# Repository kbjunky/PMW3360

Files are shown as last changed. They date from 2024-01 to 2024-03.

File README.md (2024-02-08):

# **PMW3360/PMW3389**
PMW3360/PMW3389 breakout board for trackball/mouse. Compatible with 3.3V - 5V MCUs.

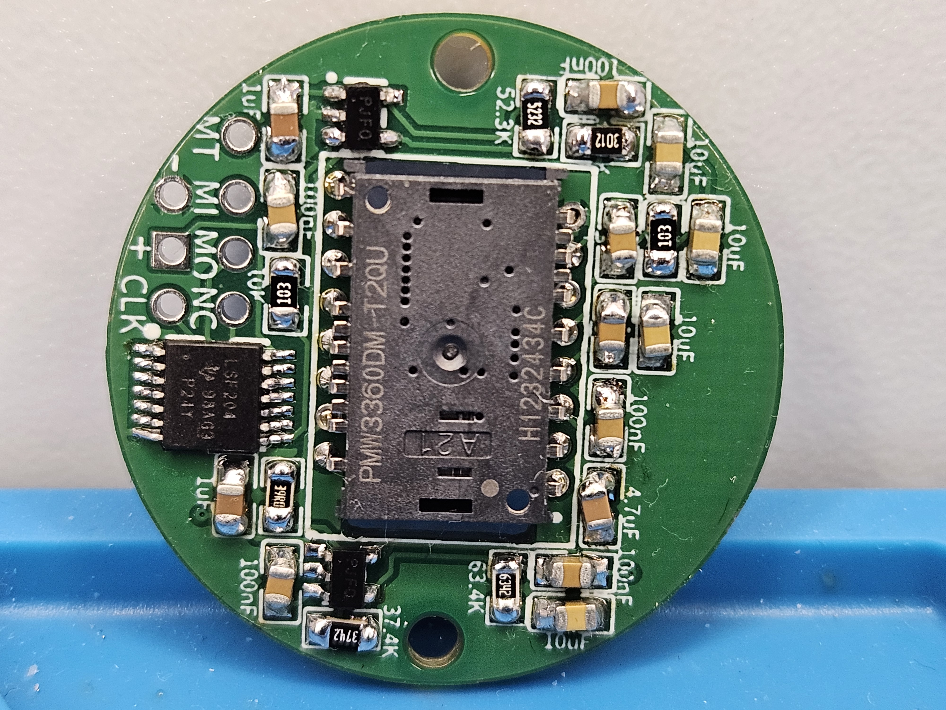
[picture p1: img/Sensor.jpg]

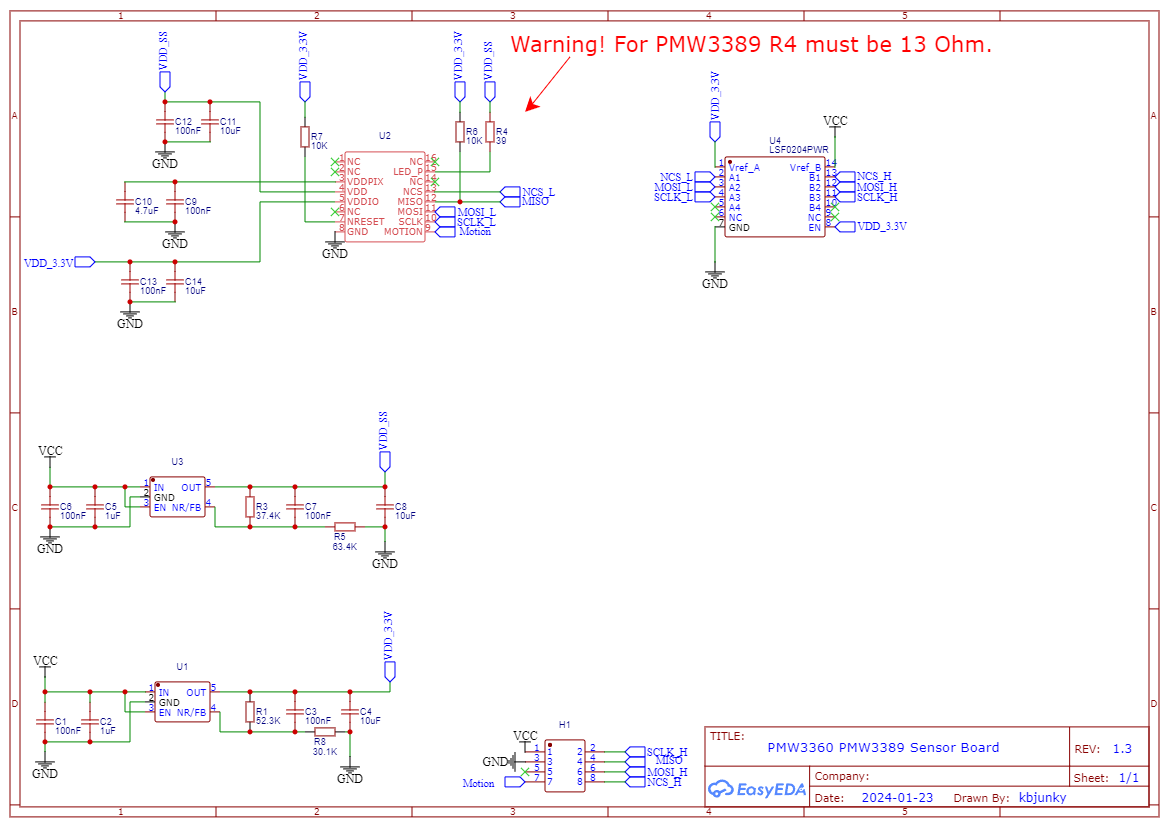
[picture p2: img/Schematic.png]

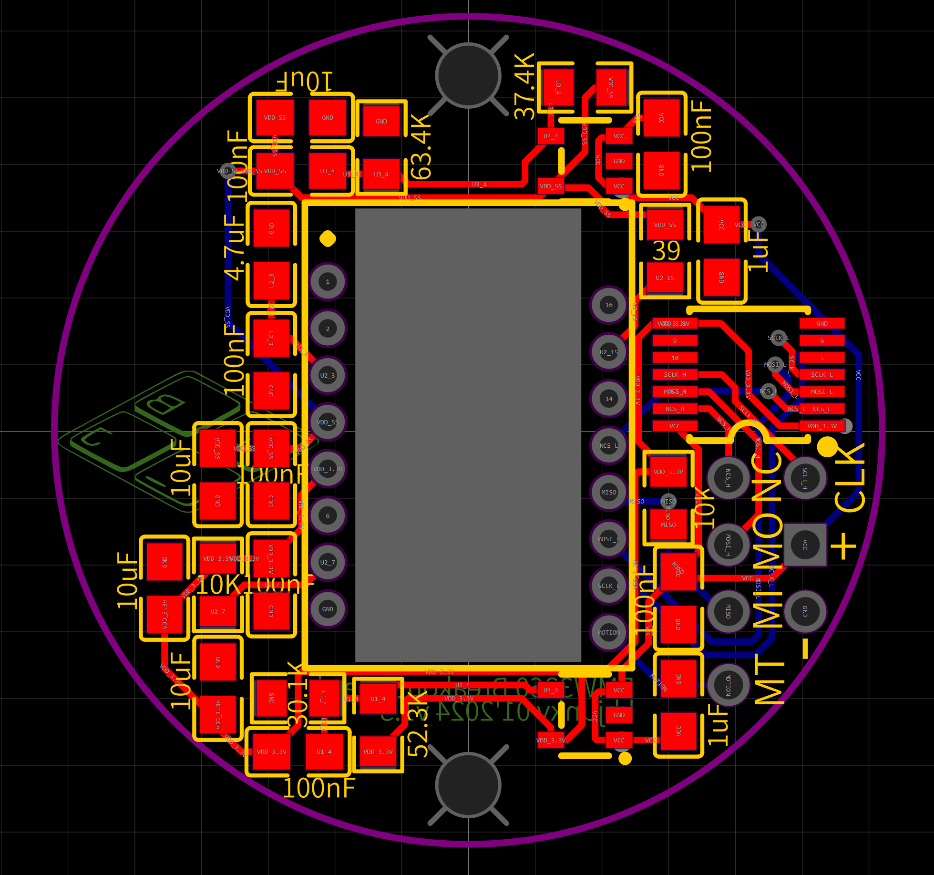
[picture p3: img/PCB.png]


## **BOM**
|Name |Value  |Footprint  |Qty |
|:---: |:---:  |:---: |:---:  |
|C1,C3,C6,C7,C9,C12,C13 |100nF  |0805 |7 |
|C2,C5 |1uF |0805 |2 |
|C4,C8,C11,C14 |10uF |0805 |4 |
|C10 |4.7uF  |0805 |1 |
|U2 | |TSSOP-14 |1 |
|R1 |52.3k  |0805 |1 |
|R3 |37.4k  |0805 |1 |
|R4 |39/13* |0805 |1 |
|R5 |63.4k  |0805 |1 |
|R6,R7 |10k |0805 |2 |
|R8 |30.1k  |0805 |1 |
|U1,U3 | |SOT23 |2 |
|PMW3360/PMW3389 + lens | | |1 |
||

Remarks:
*   PCB/Holes are the same size/placement as for [ADNS-9800](https://github.com/kbjunky/ADNS9800) thus making it easier to swap sensors for existing projects. Also in between mounting holes fits ProMicro or Rapsperry Pico thus making it possible to fit MCU underneath the sensor for a compact build.
*   U1, U3 are TPS73601DBVR LDO voltage stabilizers
*   U2 is LSF0204PWR logic level translator
*   For PMW3389 R4 must be 13 Ohm
*   Sensor together with the lens can be obtained from [Aliexpress](https://www.aliexpress.com/item/33056166849.html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)

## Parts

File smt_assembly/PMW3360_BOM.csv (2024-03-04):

ID | Name | Designator | Footprint | Quantity | Manufacturer Part | Manufacturer | Supplier | Supplier Part | Price
1 | LSF0204PWR | U4 | TSSOP-14_L5.0-W4.4-P0.65-LS6.4-BL | 1 | LSF0204PWR | TI(德州仪器) | LCSC | C202288 | 0.683
2 | 100nF | C1,C3,C6,C7,C9,C12,C13 | C0805 | 7 | FM21X104K101ECG | Prosperity Dielectrics | LCSC | C148241 | 0.006
3 | 1uF | C2,C5 | C0805 | 2 | 0805B105K160NT | FH | LCSC | C89259 | 0.01
4 | 10uF | C4,C8,C11,C14 | C0805 | 4 | 0805F106M250NT | Guangdong Fenghua Advanced Tech | LCSC | C39060 | 0.029
5 | 4.7uF | C10 | C0805 | 1 | CS2012X5R475K500NRE | Samwha Capacitor | LCSC | C513770 | 0.014
6 | 52.3K | R1 | R0805 | 1 | RTT055232FTP | RALEC | LCSC | C104392 | 0.002
7 | 37.4K | R3 | R0805 | 1 | HPCR0805F37K4K9 | ResistorToday | LCSC | C365295 | 0.011
8 | 39 | R4 | R0805 | 1 | CR0805-FX-39R0ELF | BOURNS | LCSC | C204475 | 0.012
9 | 63.4K | R5 | R0805 | 1 | WR08X6342FTL | WTC | LCSC | C170947 | 0.007
10 | 10K | R6,R7 | R0805 | 2 | RTT05103JTP | RALEC | LCSC | C103914 | 0.001
11 | 30.1K | R8 | R0805 | 1 | 0805W8F3012T5E | UniOhm | LCSC | C21841 | 0.002
12 | TPS73601DBVR | U1,U3 | SOT-23-5_L3.0-W1.7-P0.95-LS2.8-BR | 2 | TPS73601DBVR | TI | LCSC | C59200 | 0.813
13 | PMW3360DM-T2QU | U2 | PMW3360DM-T2QU.PACK | 1 | PMW3360DM-T2QU

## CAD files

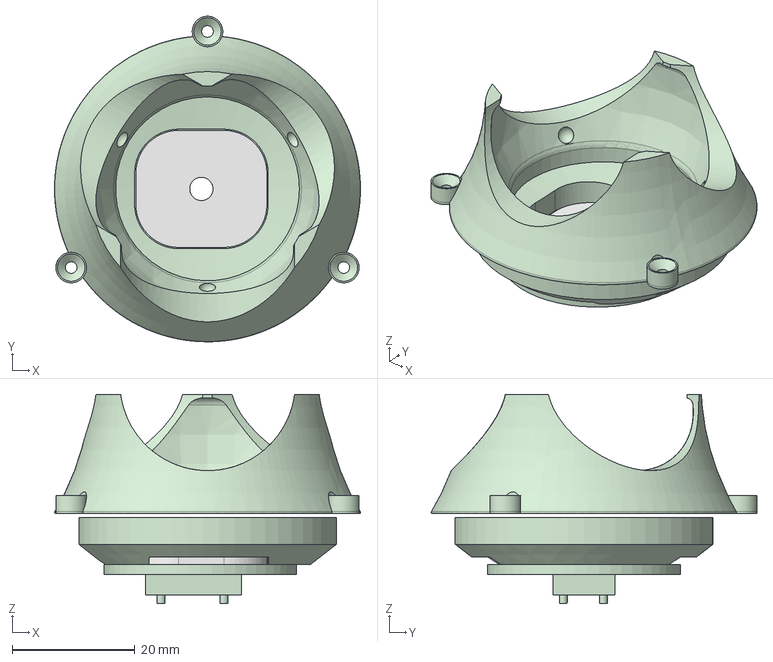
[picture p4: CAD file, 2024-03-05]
step/34mm_ball_trackball.stp
50.0 x 53.2 x 34.2 mm

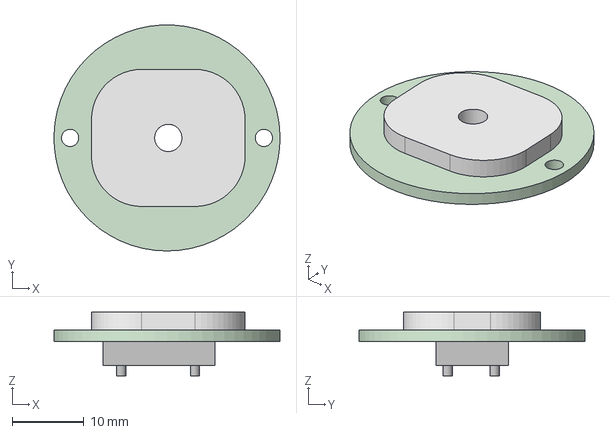
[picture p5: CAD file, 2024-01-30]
step/PMW3360.stp
31.5 x 31.5 x 8.85 mm

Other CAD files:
stl/pmw3360.stl

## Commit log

2022-11-10 Create pmw3360.stl
    Added STL for the assembled board
    [pmw3360.stl]
2024-01-30 Added step file
    [PMW3360.stp]
2024-02-08 Updated with logic shifter
    - added logic level shifter instead of Zener diodes
    - now supports PMW3389 with R4 swap to 13 Ohm
2024-03-04 Added SMT assembly required files
    +BOM
    +Pick&Place
    [PMW3360_BOM.csv, PMW3360_Pick_Place.csv]
2024-03-05 34mm ball (M570) example trackball
    [34mm_ball_trackball.stp]
